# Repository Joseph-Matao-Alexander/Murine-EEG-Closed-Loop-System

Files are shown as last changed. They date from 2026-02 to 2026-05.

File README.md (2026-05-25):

# Murine Closed-Loop EEG & Automated Pharmacotherapy System

A specialized neural engineering project designed for real-time EEG monitoring and automated drug delivery in murine (mouse) models. The system detects specific brain wave patterns and triggers a thermal-release mechanism to administer medication.

## System Logic: "The Closed-Loop"
1. **Signal Acquisition:** The system monitors EEG waves via electrodes attached to the murine subject.
2. **Analysis:** The onboard MCU processes the signal to identify target brain activity (e.g., seizure markers).
3. **Trigger:** Once the signal threshold is met, the MCU activates the heating component.
4. **Drug Delivery:** The heating element melts a specialized jelly-based medicine, releasing it to the subject.
5. **Feedback:** A temperature sensor ensures the heating remains within safe, biocompatible limits to prevent tissue damage.

## Hardware Architecture
* **MCU:** Central processing unit for signal analysis and thermal control logic.
* **Heating Component:** Integrated PCB resistor/pad designed for controlled thermal release.
* **Temperature Sensor:** High-precision sensor for real-time feedback and safety cutoff.
* **EEG Analog Front-End:** Precision amplification and filtering for microvolt-level brain signals.

## Repository Contents
* `/Murine-EEG-Closed-Loop-System.pdf`: Full technical project report and design specifications.
* `/Mouse_Project.PcbDoc`: Altium Designer PCB layout files.
* `/Mouse_Project.SchDoc`: Schematic diagrams showing the MCU-to-Heater interface.
* `/Gerber/`: Manufacturing files for the PCB.

## Safety & Biocompatibility
The system is designed to be head-mounted. The closed-loop algorithm includes a "Thermal Guard" feature: the MCU continuously polls the temperature sensor to ensure the heating element never exceeds the programmed safety threshold, protecting the subject while ensuring effective drug release.

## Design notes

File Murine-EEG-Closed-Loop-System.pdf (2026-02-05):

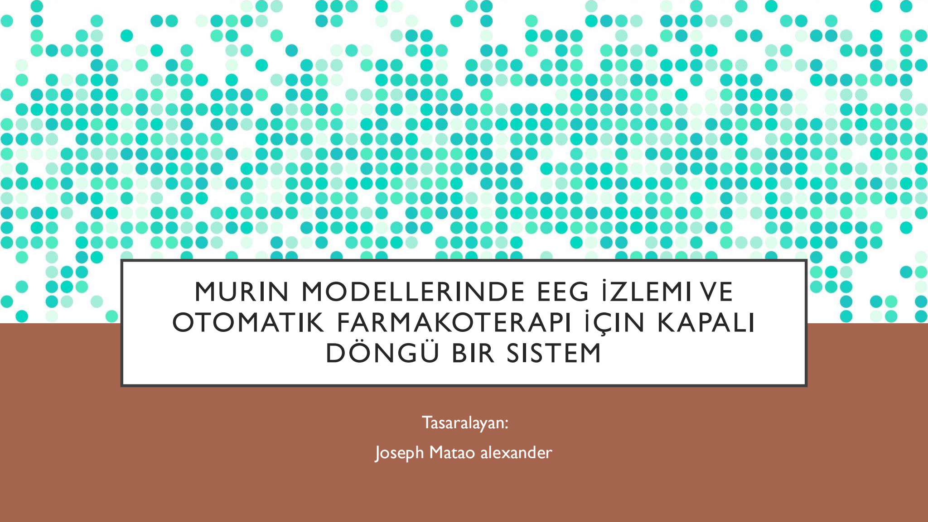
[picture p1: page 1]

## MURIN MODELLERINDE EEG İZLEMI VE OTOMATIK FARMAKOTERAPI İÇIN KAPALI DÖNGÜ BIR SISTEM

Tasaralayan:

Joseph Matao alexander

## YÜKSELTİÇ DEVRESİ

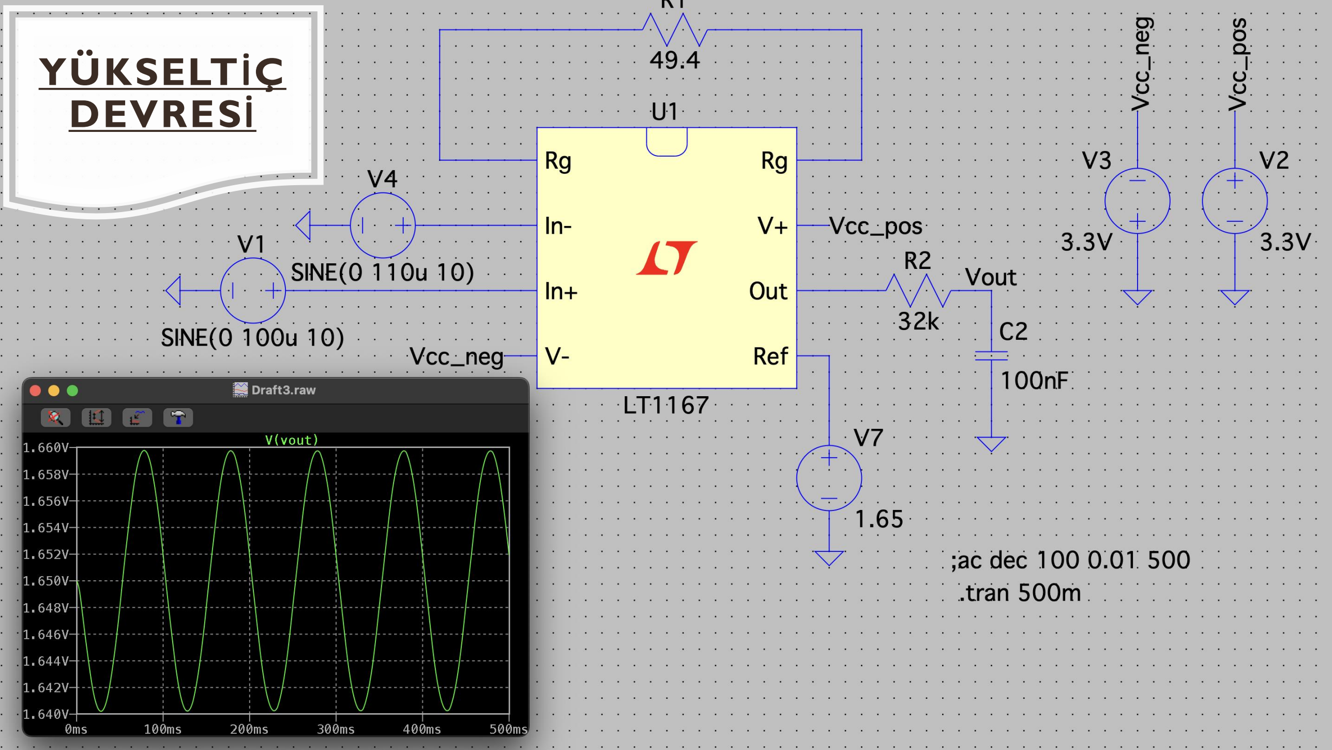
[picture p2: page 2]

## ALÇAK GEÇİREN

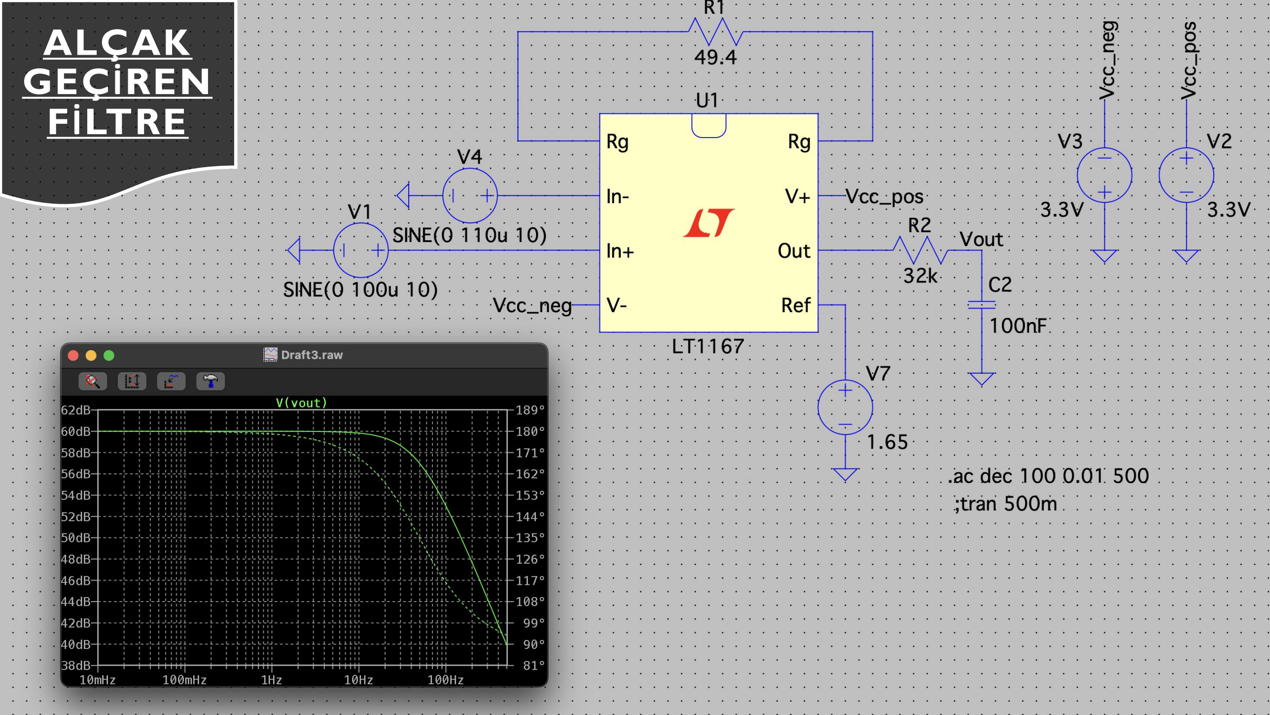
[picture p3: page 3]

## FİLTRE

## NEDEN LT1167 KULLANDIK?

Yüksek Hassasiyet:

- Mikro-Volt Seviyesinde Kazanç: Beyin dalgaları (10µV) çok küçüktür; LT1167 bu sinyalleri mikroişlemcinin okuyabileceği seviyeye getirir.
- Tek Dirençle Kontrol: Sadece 49.4Ω direnç kullanarak tam 1001 kat (60dB) kazanç elde edilmiştir.

G = 1 + (49.4K/Rg)

Rg = 49.4Ω, G = 1001

## NEDEN LT1167 KULLANDIK?

GürültüTemizleme (CMRR Teknolojisi - Common Mode Rejection Ratio)

- Ortak Mod Reddi: Kablolara dışarıdan (prizlerden, lambalardan) vuran gürültüleri ayıklar, sadece saf beyin sinyalini büyütür.
- Net Veri: Gürültüyü sinyalden 300.000 kat daha fazla baskılayarak temiz bir veri akışı sağlar.

## NEDEN LT1167 KULLANDIK?

Sanal Toprak (1.65 V) ve MCU Koruması

- Sinyal Kaydırma: ESP32-C3 negatif voltajları okuyamaz (0 - 3.3V arası çalışır).
- Sıfır Noktası: Sinyalin merkezini 1.65V seviyesine taşıyarak, dalgaların işlemci tarafından kesintisiz ve güvenli bir şekilde okunmasını sağlar.

## NEDEN LT1167 KULLANDIK?

### 50Hz Alçak Geçiren Filtre

- Sinyal Sınırlandırma: Kas hareketleri ve yüksek frekanslı parazitleri engellemek için 32k ve 100nF bileşenleriyle filtreleme yapılmıştır.

f = 1/(2*pi*R*C) = 1/(2*3.14*32k*100*10^-9) = 49.76

- Veri Kalitesi: 50Hz üzerindeki gereksiz verileri atarak sadece anlamlı EEG dalgalarına odaklanır.

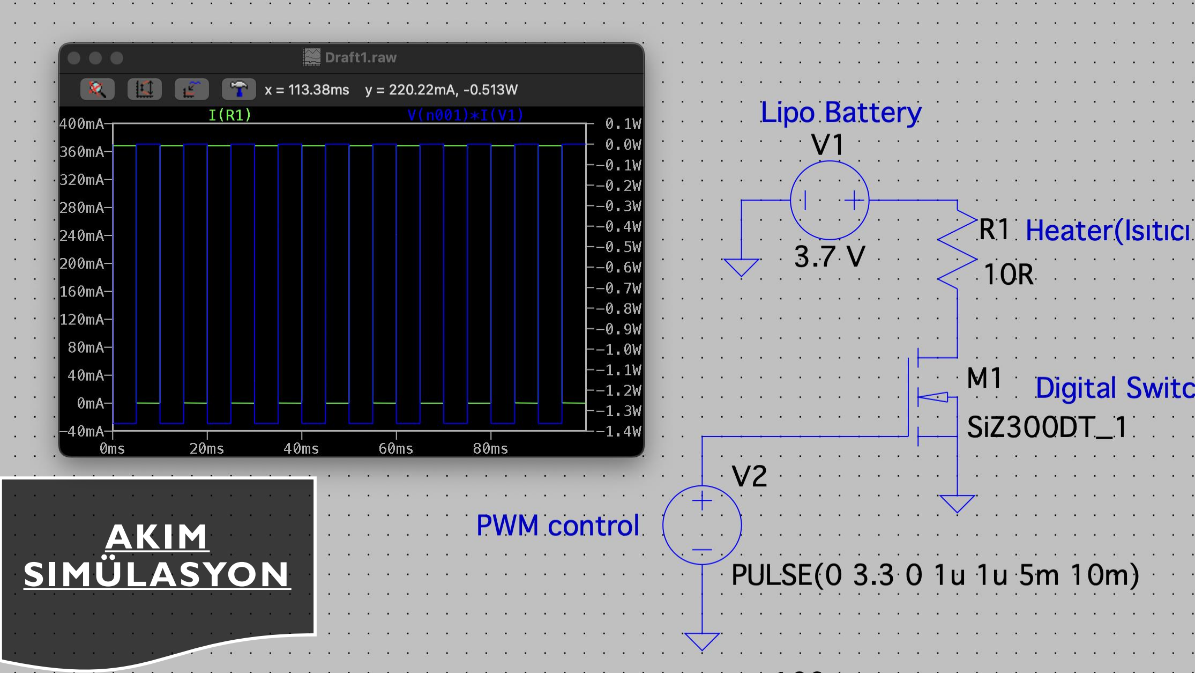
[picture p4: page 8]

## AKIM SIMÜLASYON

## AKIM HESAPLAMALARI

- Şekil 1:Daha düşük iç direnç sayesinde 370mA akım elde edilmiştir.
- IR1 =

3.7v
10+0.05 Ω

= 370mA

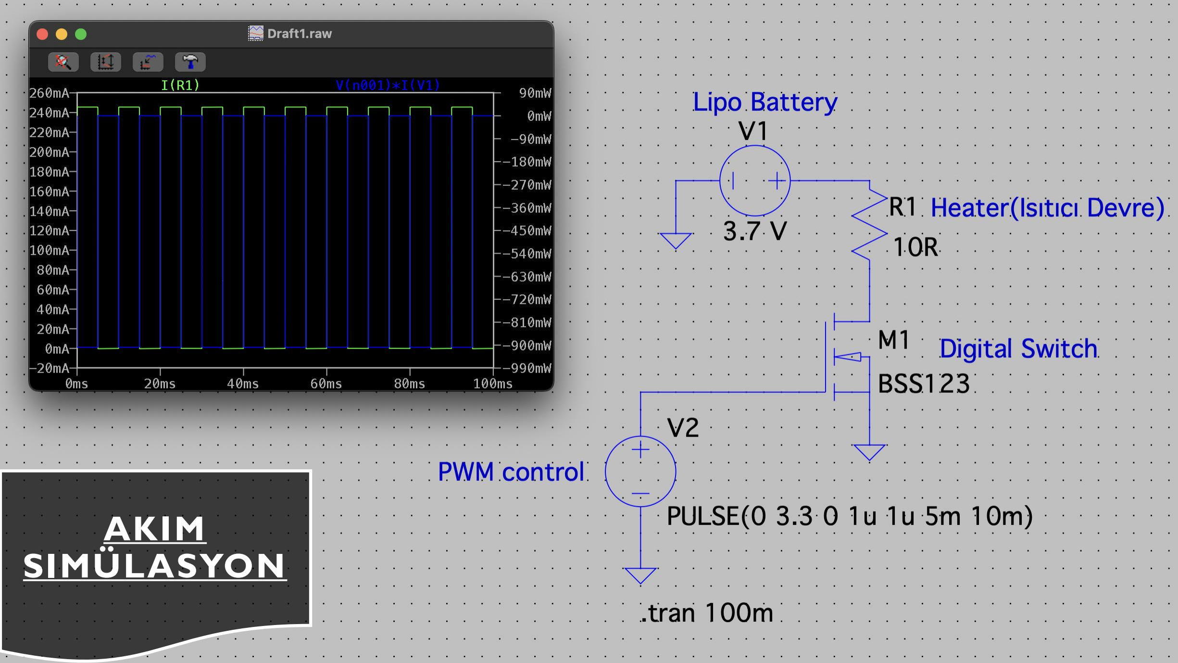
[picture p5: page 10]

## AKIM SIMÜLASYON

## AKIM HESAPLAMALARI

- Şekil 2 (BSS123): Daha yüksek iç direnç nedeniyle akım 240 mA seviyesine düşmüştür.
- IR1 =

3.7v
10+6 Ω

= 240mA

- Sonuç: Maksimum ısıtma performansı için düşük dirençli anahtarlama elemanları tercih edilmelidir.

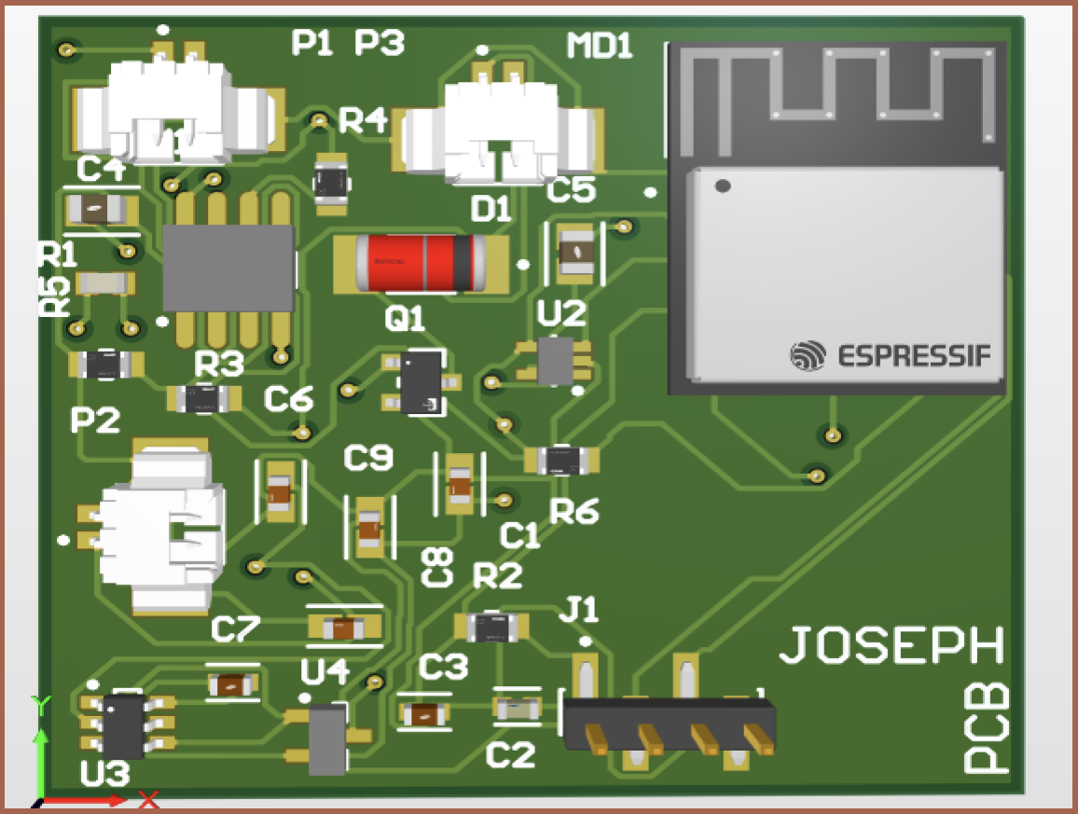
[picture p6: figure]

## 3 BOYUTLU

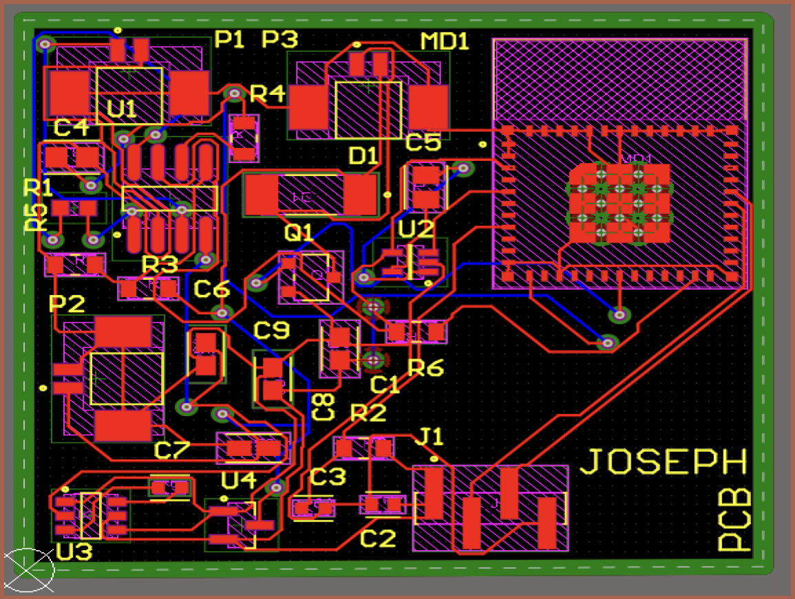
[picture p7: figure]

## PCB (4 KATMANLI)

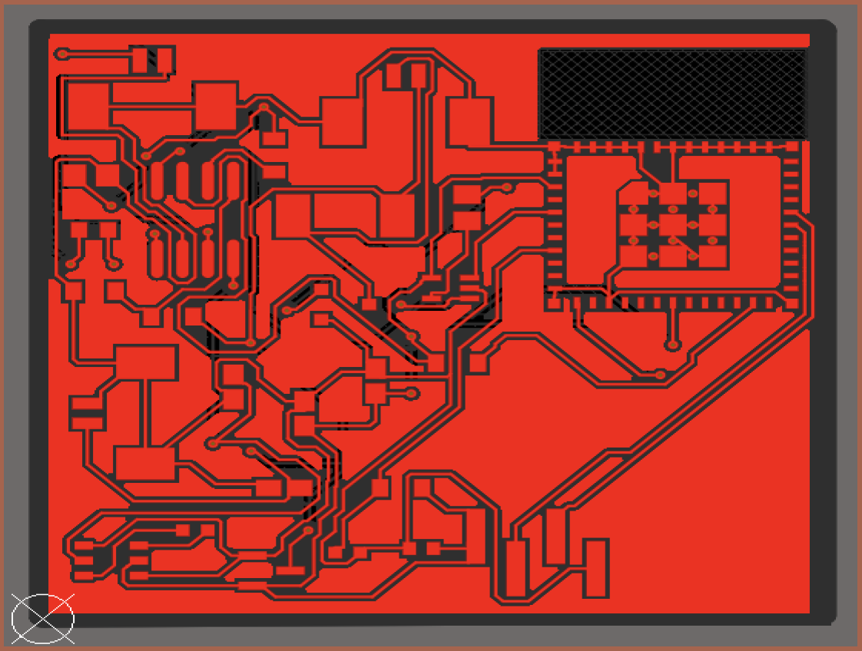
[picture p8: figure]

## TOP LAYER

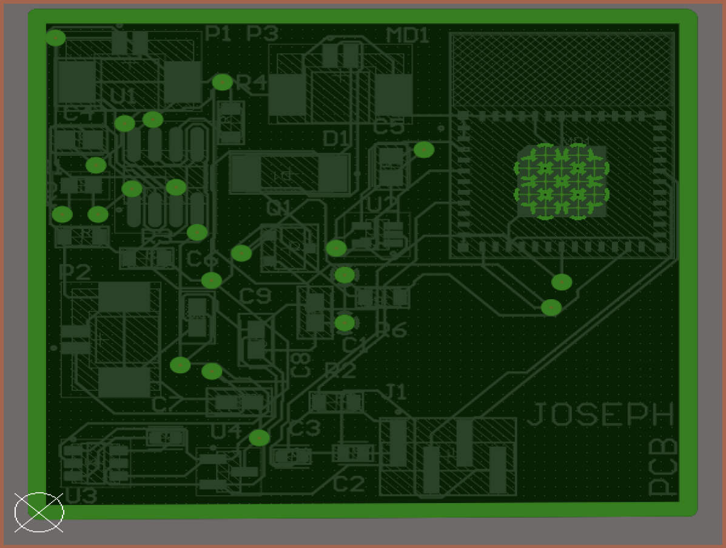
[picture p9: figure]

## 2 LAYER(GND)

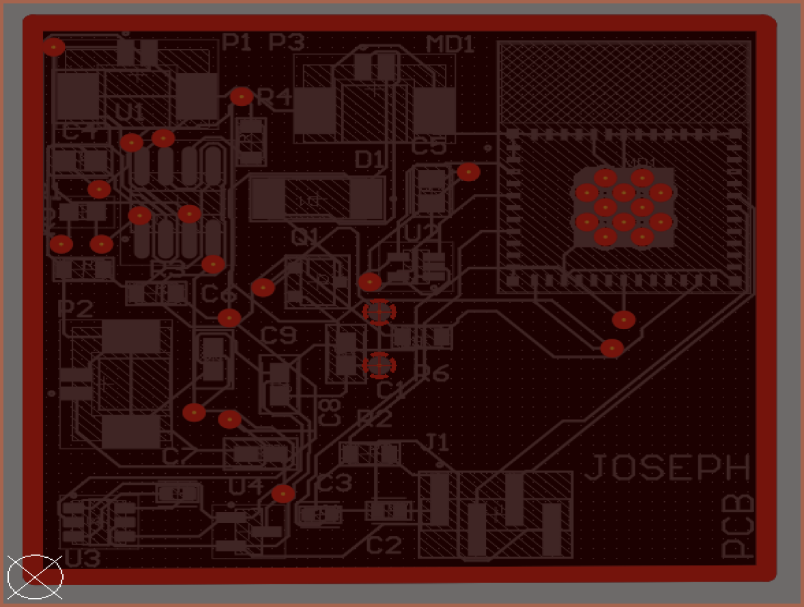
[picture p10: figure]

## 2 LAYER(GND)

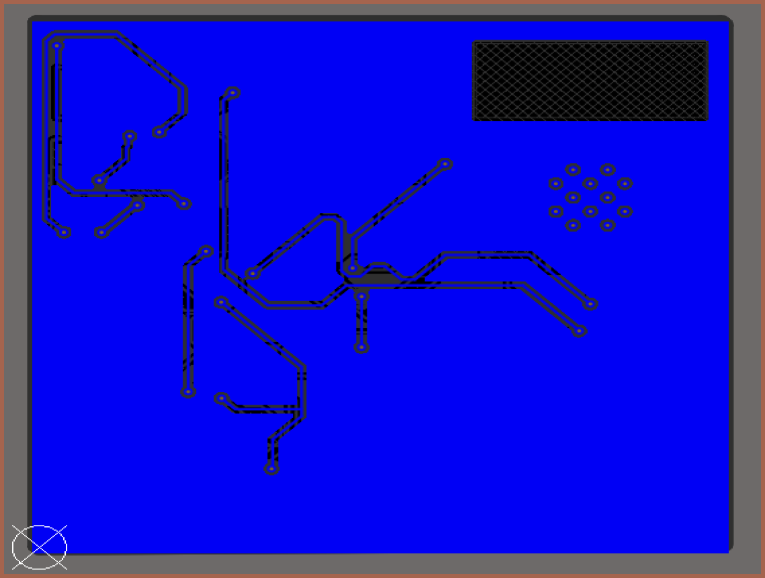
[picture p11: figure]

## BOTTOM LAYER(GND)

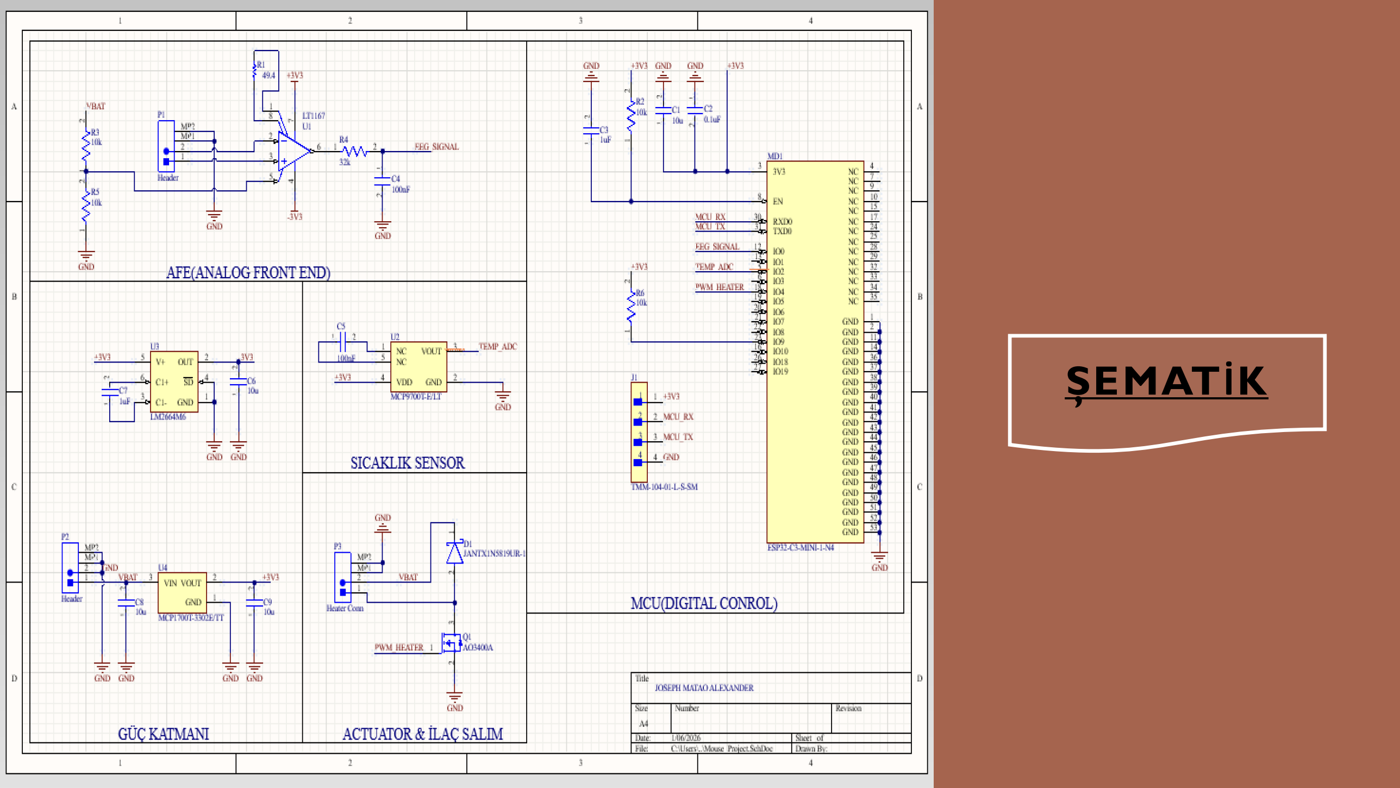
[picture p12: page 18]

## ŞEMATİK

## GÜÇ KATMANI

- Sistemin ihtiyaç duyduğu kararlı voltajları üreten bölümdür.
- Regülasyon: Batarya veya ana besleme girişinden gelen voltajı, devre elemanlarının (MCU ve sensörler) çalışması için gereken sabit 3.3V seviyesine düşürür.
- Gürültü Engelleme: Kondansatörler (decoupling caps) kullanılarak güç hattındaki dalgalanmaların hassas ölçüm devresini etkilemesi önlenir.

## ACTUATOR & İLAÇ SALIMI

- Mikrodenetleyiciden gelen komutları fiziksel bir eyleme dönüştüren kısımdır.
- Kontrol Mekanizması: MCU'dan gelen PWM (Sinyal Genişlik Modülasyonu) sinyali ile bir MOSFET veya sürücü tetiklenir.
- İşlev: Bu tetikleme sayesinde ısıtıcı veya pompa gibi bir eleman çalıştırılarak hassas miktarda ilaç salımı veya mekanik bir hareket gerçekleştirilir.

## DESIGN RULE CHECK(DRC)

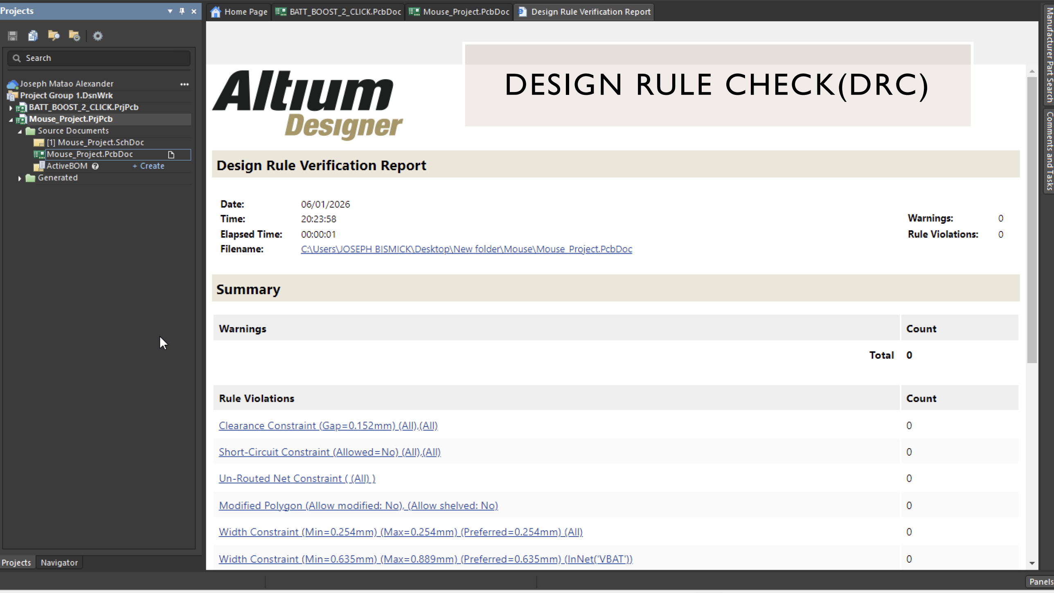
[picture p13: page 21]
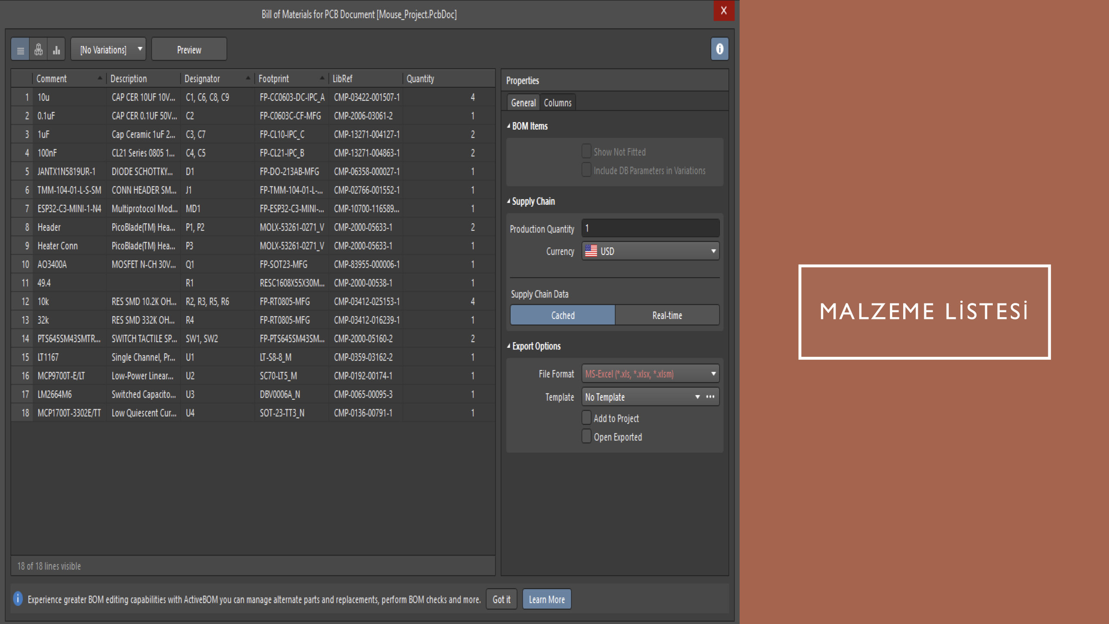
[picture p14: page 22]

MALZEME LİSTESİ

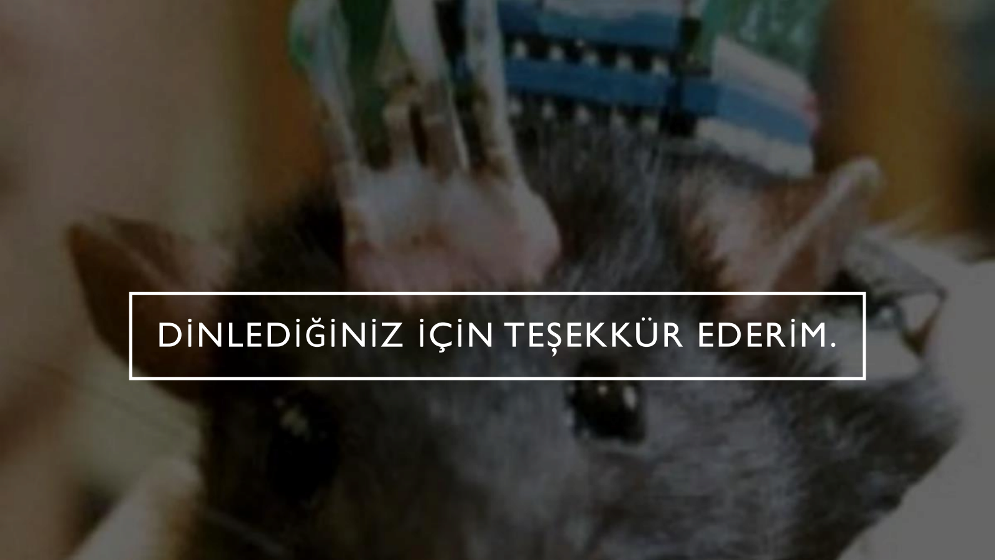
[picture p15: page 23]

DİNLEDİĞİNİZ İÇİN TEŞEKKÜR EDERİM.

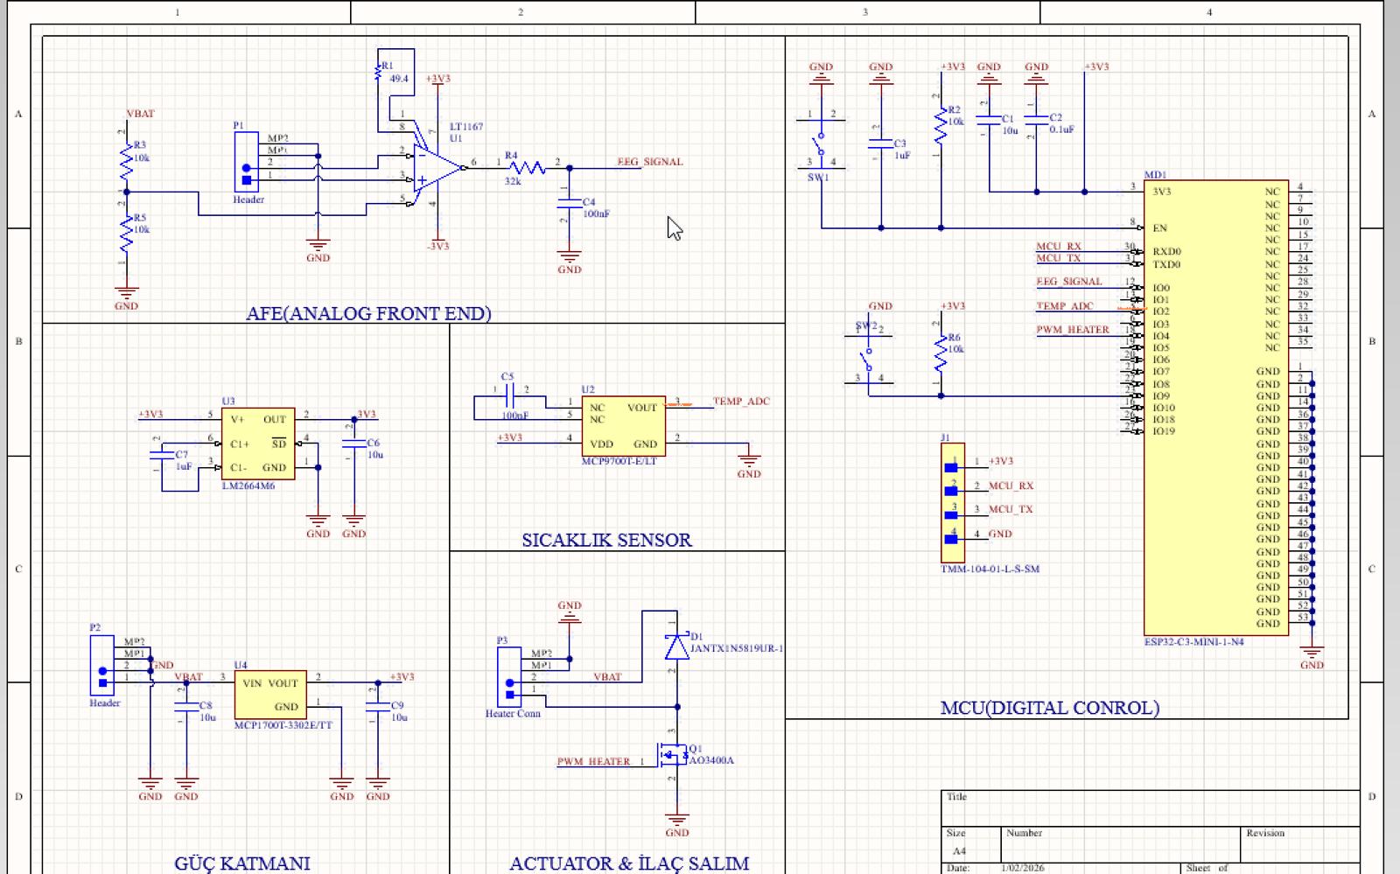
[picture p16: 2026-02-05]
prototype_schematic.jpg

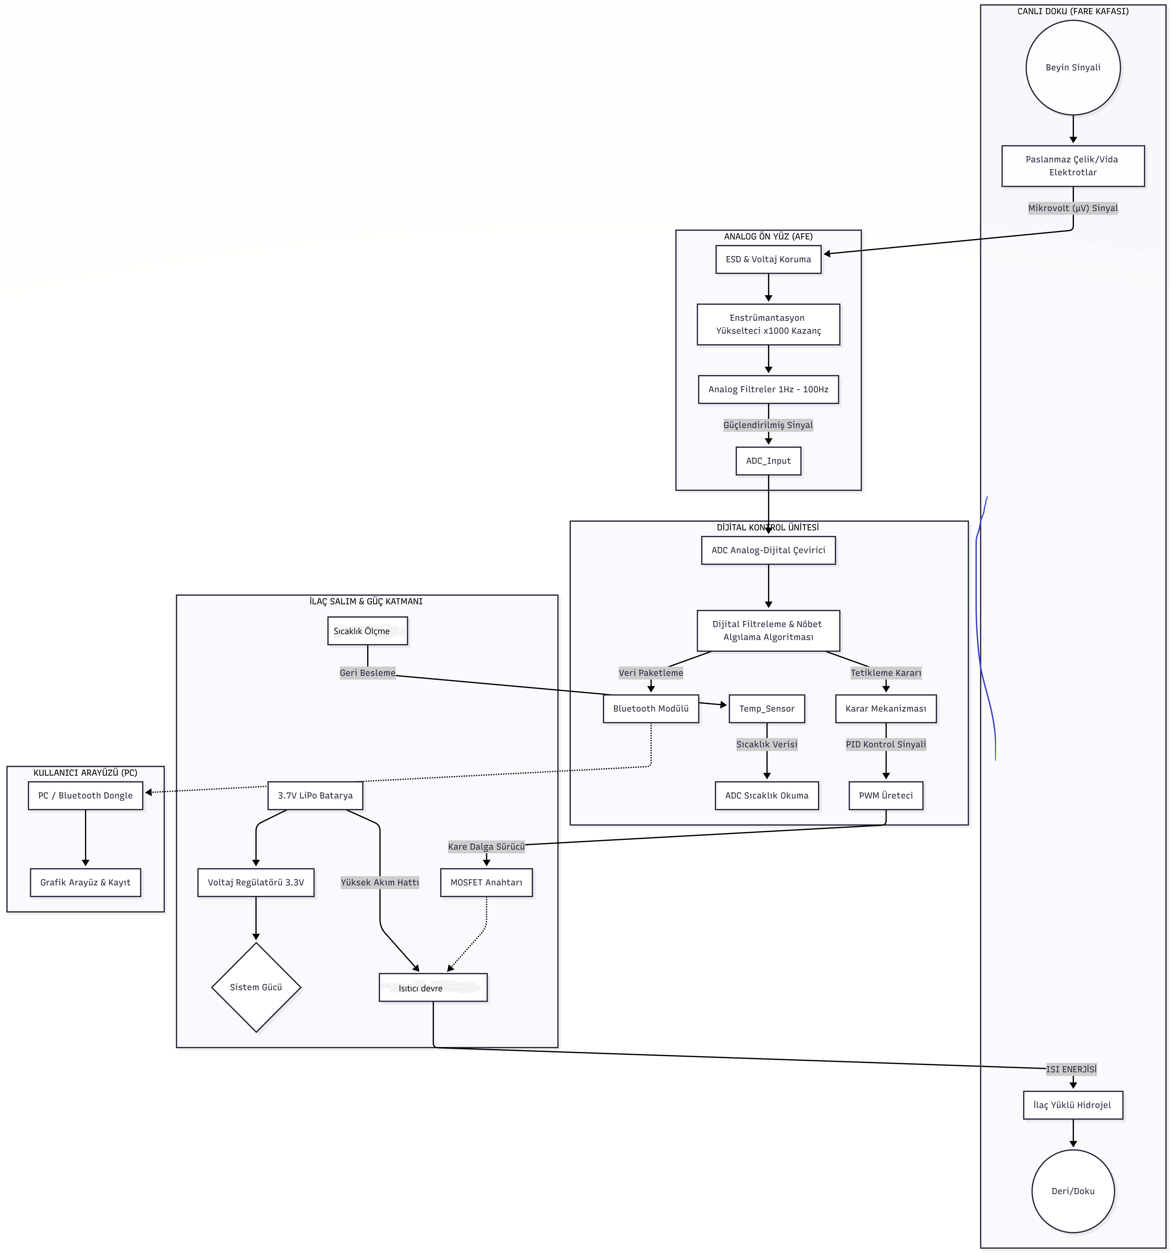
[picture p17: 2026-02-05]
Proje blok diyagramı.png
